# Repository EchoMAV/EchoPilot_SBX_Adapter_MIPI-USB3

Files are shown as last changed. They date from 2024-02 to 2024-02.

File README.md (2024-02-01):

Created using KiCad 7.0.10

This is an open-source payload/camera adapter designed for the EchoPilot SBX series of boards. It is meant for a 2 or 4-lane MIPI camera (22 pin 0.5mm spacing, standard Nvidia and Rpi pinout) and an optional FLIR boson in conjunction with OEM Camera VPC3 board (https://www.oemcameras.com/rhp-bos-vpc3-if.htm?search=vpc). The board also includes a 100Mbps Ethernet port using a JST GH connector.

6 Layer PCB, 4/4 mil spacing, min hole size is 0.2mm
Note impedance controlled traces for MIPI, USB and Ethernet. Trace width and spacing may need to be adjusted depending on the stackup and materials used in production.

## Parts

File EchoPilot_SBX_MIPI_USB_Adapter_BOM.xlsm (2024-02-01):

EchoPilot SBX MIPI/USB3 Adapter
Rev 0
Item | Qty | Reference(s) | Value | LibPart | Footprint | Part Num
1 | 1 | C1 | 0.1uF | Device:C | Capacitor_SMD:C_0201_0603Metric | GRM033R61E104KE14J
2 | 1 | D1 | LED | Device:LED | LED_SMD:LED_0603_1608Metric | 150060VS75000
3 | 1 | J1 | 2-1734592-2 | Connector_Generic:Conn_01x22 | UVDL.Pretty:CONN22_2-1734592-2 | 2-1734592-2
4 | 1 | J2 | DF40GB-70DP-0.4V(58) | Connector_Generic_Shielded:Conn_02x35_Top_Bottom_Shielded | UVDL.Pretty:DF40GB70DP04V58_REV1 | DF40GB-70DP-0.4V(58)
5 | 1 | J3 | Conn_01x07 | Connector_Generic:Conn_01x07 | Connector_JST:JST_SH_SM07B-SRSS-TB_1x07-1MP_P1.00mm_Horizontal | SM07B-SRSS-TB
6 | 1 | J4 | Conn_01x04 | Connector_Generic:Conn_01x04 | Connector_JST:JST_GH_BM04B-GHS-TBT_1x04-1MP_P1.25mm_Vertical | BM04B-GHS-TBT
7 | 1 | R1 | 1.0K | Device:R | Resistor_SMD:R_0201_0603Metric | ERJ-1GEF1001C

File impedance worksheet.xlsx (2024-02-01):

Impedance Worksheet
EchoPilot SBX MIPI/USB3 Payload Board
Note: Impedance controlled traces can be identified using the unique trace widths specified below.
USB | Target 90
Type | Diff Pair
Routing Layer | Reference | Stackup Space | Width | Spacing
L1 | L2 | 0.11 | 5.7 | 5
L6 | L5 | 0.11 | 5.7 | 5
Ethernet | Target 100
Type | Diff Pair
Routing Layer | Reference | Stackup Space | Width | Spacing
L1 | L2 | 0.11 | 5.2 | 6.8
L6 | L5 | 0.11 | 5.2 | 6.8
MIPI | Target 100
Type | Diff Pair
Routing Layer | Reference | Stackup Space | Width | Spacing
L1 | L2 | 0.11 | 5.2 | 6.8
L3 | L2 | 0.2 | 4.4 | 9.9
L4 | L5 | 0.2 | 4.4 | 9.9
L6 | L5 | 0.11 | 5.2 | 6.8

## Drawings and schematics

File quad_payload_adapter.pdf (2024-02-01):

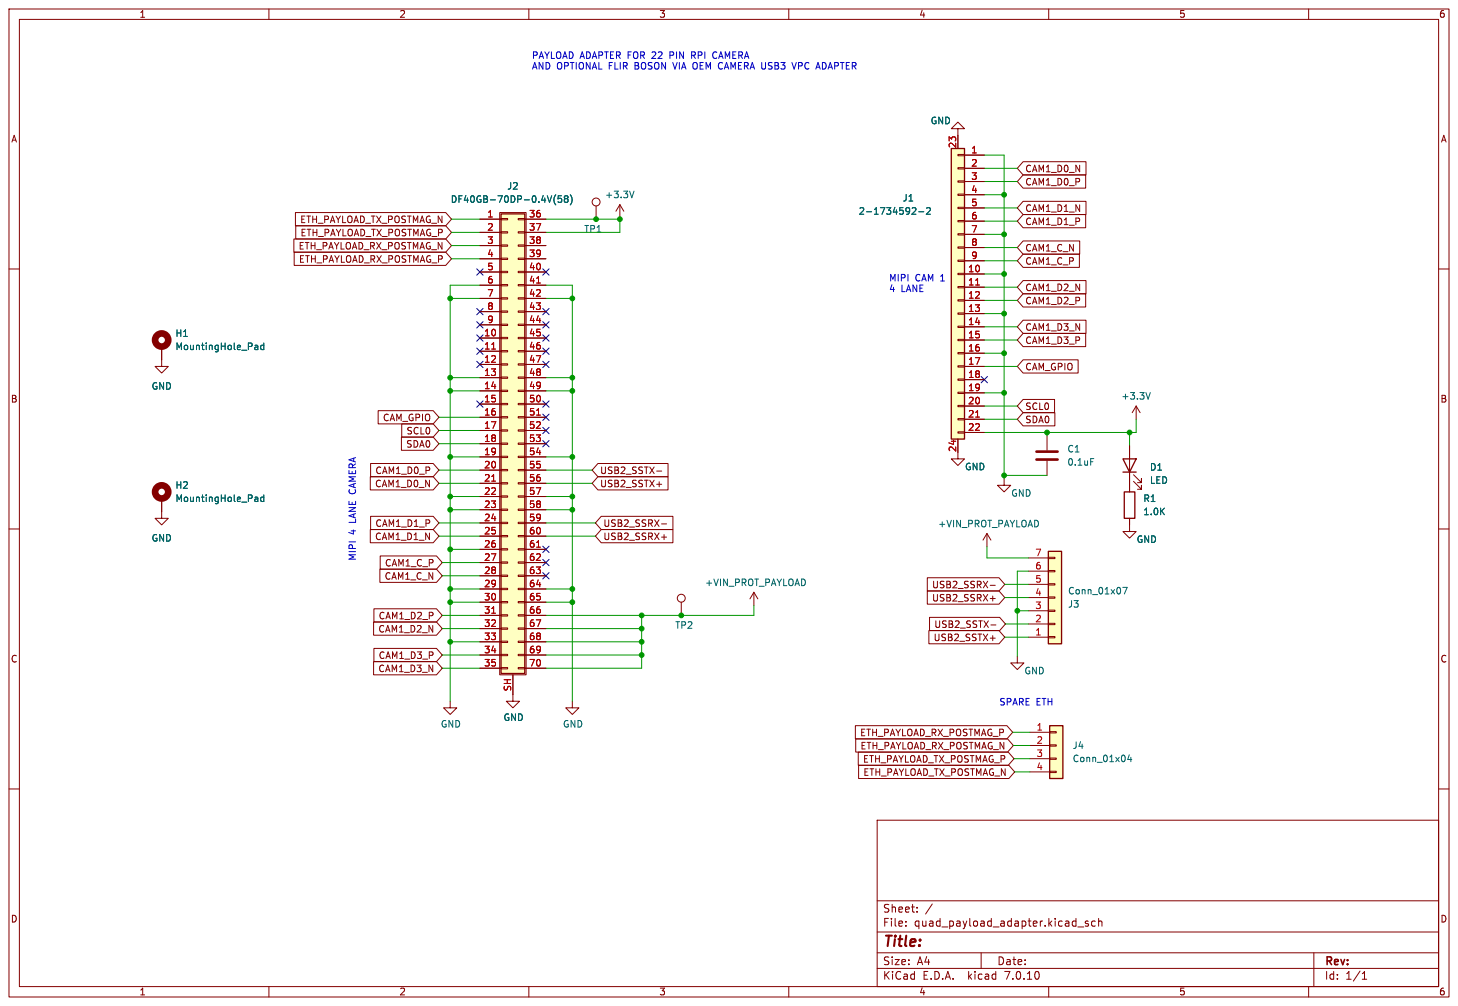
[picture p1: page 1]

SPARE ETH GND GND GND

Id: 1/1 Title: File: quad_payload_adapter.kicad_sch Sheet: /

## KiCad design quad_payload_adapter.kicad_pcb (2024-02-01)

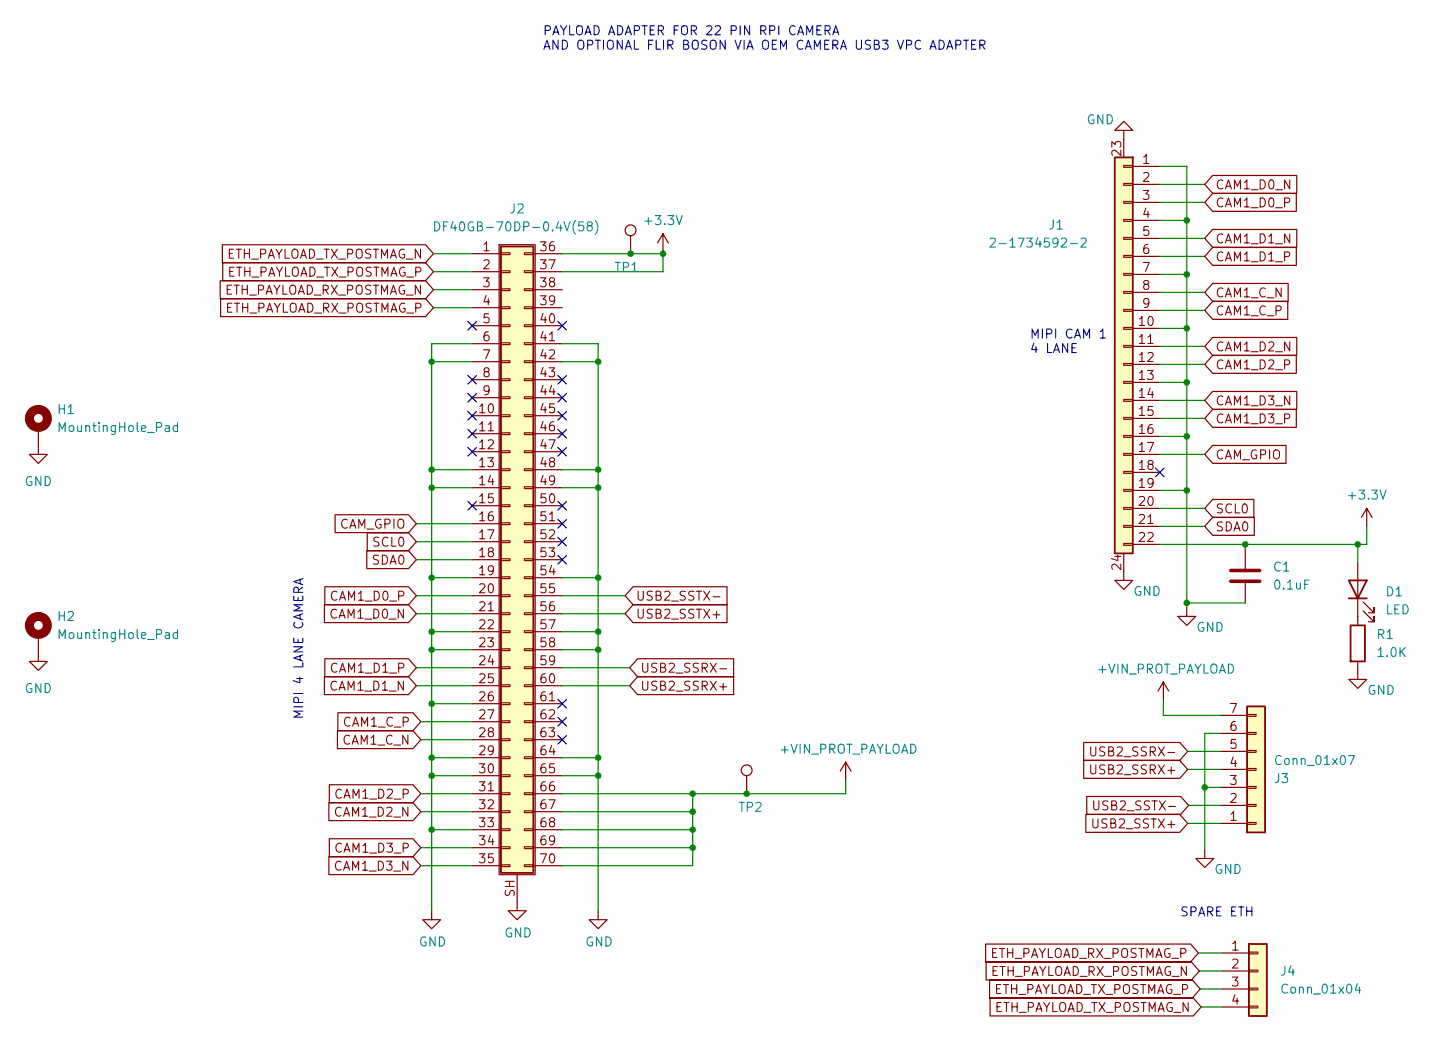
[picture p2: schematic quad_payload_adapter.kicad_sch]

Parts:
C1: 0.1uF; C_0201_0603Metric; Part Num GRM033R61E104KE14J
D1: LED; LED_0603_1608Metric; Part Num 150060VS75000
H1, H2: MountingHole_Pad; MountingHole_2.2mm_M2_Pad
J1: 2-1734592-2; CONN22_2-1734592-2; Part Num 2-1734592-2
J2: DF40GB-70DP-0.4V(58); DF40GB70DP04V58_REV1; Part Num DF40GB-70DP-0.4V(58)
J3: Conn_01x07; JST_SH_SM07B-SRSS-TB_1x07-1MP_P1.00mm_Horizontal; Part Num SM07B-SRSS-TB
J4: Conn_01x04; JST_GH_BM04B-GHS-TBT_1x04-1MP_P1.25mm_Vertical; Part Num BM04B-GHS-TBT
R1: 1.0K; R_0201_0603Metric; Part Num ERJ-1GEF1001C
TP1, TP2: TestPoint; TestPoint_Pad_D1.0mm; Part Num DNI

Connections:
+3.3V: C1.1, D1.2 (A), J1.22, J2.36, J2.37, TP1.1
+VIN_PROT_PAYLOAD: J2.66, J2.67, J2.68, J2.69, J2.70, J3.7, TP2.1
CAM1_C_N: J1.8, J2.28
CAM1_C_P: J1.9, J2.27
CAM1_D0_N: J1.2, J2.21
CAM1_D0_P: J1.3, J2.20
CAM1_D1_N: J1.5, J2.25
CAM1_D1_P: J1.6, J2.24
CAM1_D2_N: J1.11, J2.32
CAM1_D2_P: J1.12, J2.31
CAM1_D3_N: J1.14, J2.35
CAM1_D3_P: J1.15, J2.34
CAM_GPIO: J1.17, J2.16
ETH_PAYLOAD_RX_POSTMAG_N: J2.3, J4.2
ETH_PAYLOAD_RX_POSTMAG_P: J2.4, J4.1
ETH_PAYLOAD_TX_POSTMAG_N: J2.1, J4.4
ETH_PAYLOAD_TX_POSTMAG_P: J2.2, J4.3
GND: C1.2, H1.1, H2.1, J1.1, J1.4, J1.7, J1.10, J1.13, J1.16, J1.19, J1.23 (S1), J1.24 (S2), J2.6, J2.7, J2.13, J2.14, J2.19, J2.22, J2.23, J2.26, J2.29, J2.30, J2.33, J2.41, J2.42, J2.48, J2.49, J2.54, J2.57, J2.58, J2.64, J2.65, J2.SH (Shield), J3.3, J3.6, R1.2
unnamed: D1.1 (K), R1.1
SCL0: J1.20, J2.17
SDA0: J1.21, J2.18
USB2_SSRX+: J2.60, J3.4
USB2_SSRX-: J2.59, J3.5
USB2_SSTX+: J2.56, J3.1
USB2_SSTX-: J2.55, J3.2

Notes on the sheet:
PAYLOAD ADAPTER FOR 22 PIN RPI CAMERA AND OPTIONAL FLIR BOSON VIA OEM CAMERA USB3 VPC ADAPTER
MIPI CAM 1 4 LANE
MIPI 4 LANE CAMERA
SPARE ETH

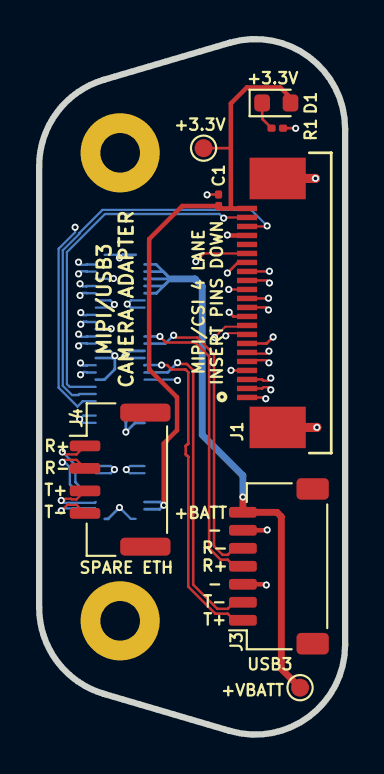
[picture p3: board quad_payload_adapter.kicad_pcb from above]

Board: 6 copper layers, 17.0 x 38.6 mm, 11 parts (1 on the bottom side), 25 nets.

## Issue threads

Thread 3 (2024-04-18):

camera connector

climr, 2024-04-18:
switch to rpi standard, https://www.digikey.com/en/products/detail/molex/0545482271/3196988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

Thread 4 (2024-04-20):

3.3V protect

climr, 2024-04-20:
need current limit on 3.3V, otherwise plugging in a cable backwards results in a melted cable
